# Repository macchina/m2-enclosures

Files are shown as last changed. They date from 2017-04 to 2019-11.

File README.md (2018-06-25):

# M2 Enclosures

We've designed a few 3-D printable enclosures that fit M2. Feel free to print, edit, tweak and share what you've made!

This repository contains 4 possible case variations:

* Under-the-hood (UTH) 
* Under-the-hood (UTH) with additional space for XBee modules
* Under-the-dash (UTD)
* Under-the-dash (UTD) with additional space for XBee modules

Any Gcode files are created with Cura for use on an Ultimaker 2 machine. Unless you have the same machine, you'll probably want to re-slice from STL file for your machine.

#### Note: Use the latest M2R3 versions for best fitting enclosures ####

 Our release hardware uses V-scored PCBs, which result in a little more material on the edges of the PCBs. We've updated the enclosure design to address this, so please use the "M2R3" versions.

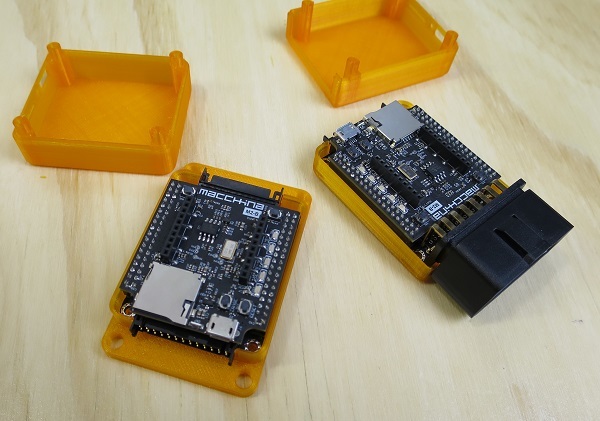
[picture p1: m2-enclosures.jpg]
Picture of printed cases


 We used 4 of [these](https://www.mcmaster.com/#90380a011/=179tb2t) screws in each assembly. We like this translucent plastic so you can see the 5 single-color LEDs through the case. These were printed on an Ultimaker 2 machine.

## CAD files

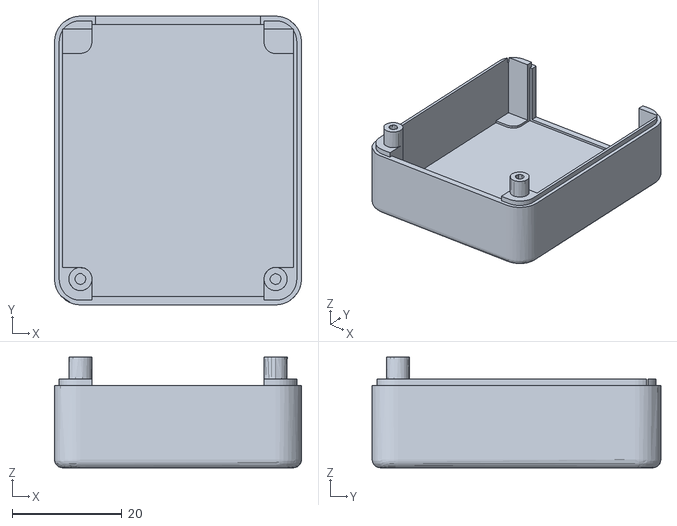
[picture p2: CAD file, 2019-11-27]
P1BETA-UTH_TOP.stl
45.0 x 52.6 x 20.1

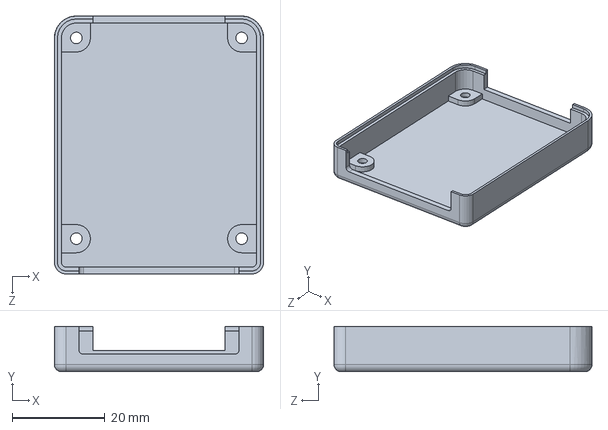
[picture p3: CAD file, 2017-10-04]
M2R3_CASE_BOTTOM_UTD.SLDPRT
45.0 x 9.75 x 55.5 mm

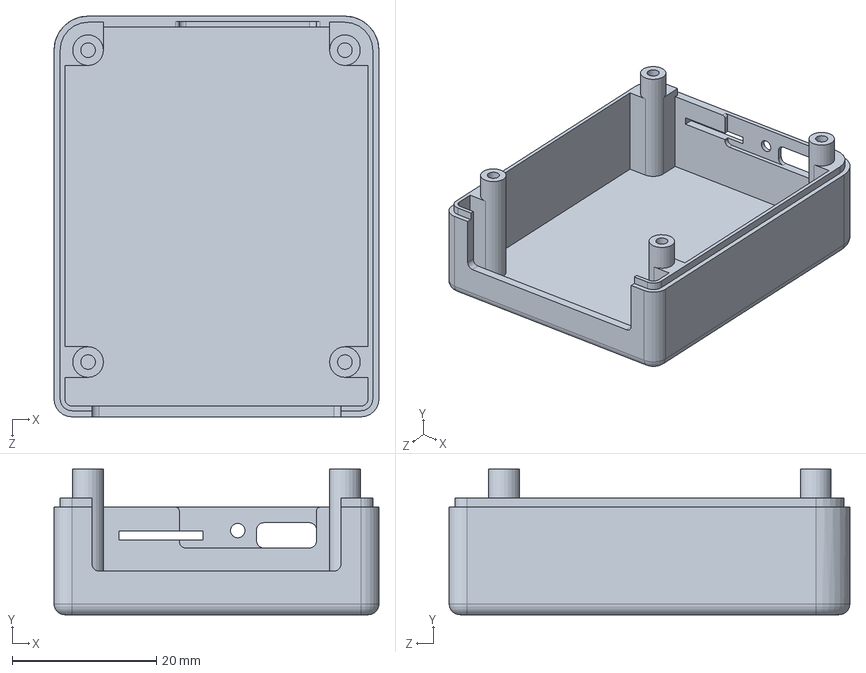
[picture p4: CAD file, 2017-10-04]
M2R3_CASE_TOP_UTD.SLDPRT
45.0 x 20.1 x 55.5 mm

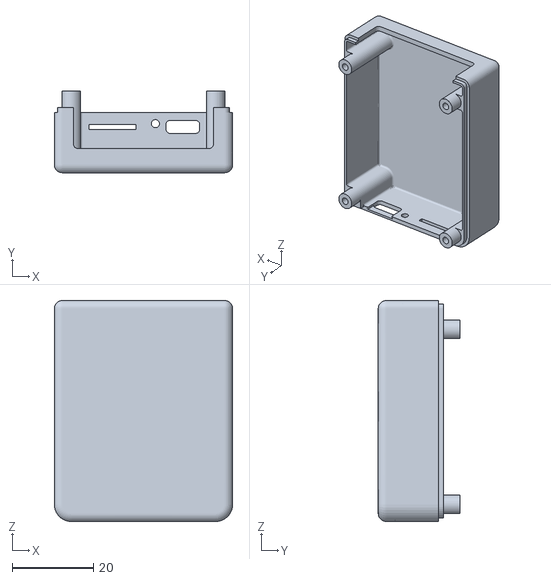
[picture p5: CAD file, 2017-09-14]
M2R2_XBEE_CASE_TOP_UTD.stl
44.0 x 20.1 x 54.5

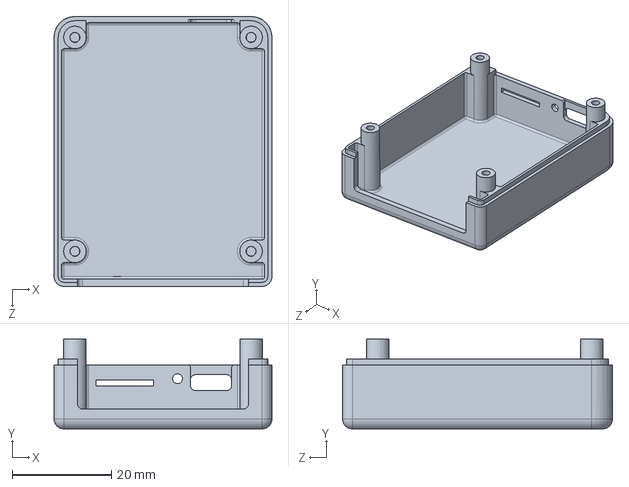
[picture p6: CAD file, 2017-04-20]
M2R2_CASE_TOP_UTD.SLDPRT
44.0 x 18.1 x 54.5 mm

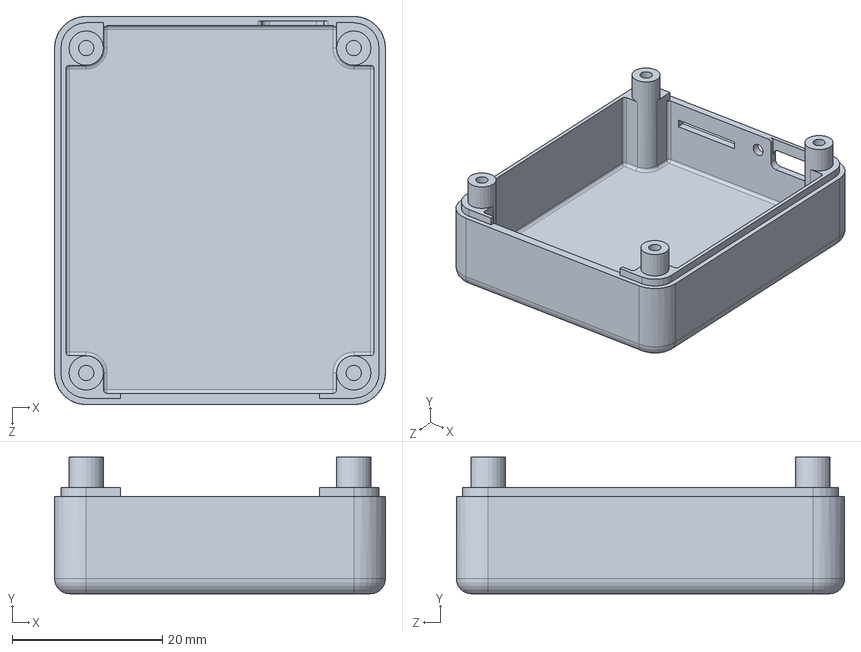
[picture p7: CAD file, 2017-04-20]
M2R2_CASE_TOP_UTH.SLDPRT
44.0 x 18.1 x 51.6 mm

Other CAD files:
ARCHIVE/M2R2_CASE_BOTTOM_UTH.STL
ARCHIVE/M2R2_CASE_TOP_UTD.STL
ARCHIVE/M2R2_CASE_TOP_UTH.STL
ARCHIVE/M2R3_CASE_BOTTOM_UTD.STL
ARCHIVE/M2R3_CASE_TOP_UTD.STL
M2R2_CASE_BOTTOM_UTH.STL
M2R2_CASE_TOP_UTD.STL
M2R2_CASE_TOP_UTH.STL
M2R3_CASE_BOTTOM_UTD.STL
M2R3_CASE_TOP_UTD.STL
M2R3_UTD_BOTTOM.STL
M2R3_UTD_TOP.STL
M2R3_UTD_TOP_SHORT.STL
M2R3_UTH_BOTTOM.STL
M2R3_UTH_TOP.STL
M2R3_UTH_TOP_SHORT.STL

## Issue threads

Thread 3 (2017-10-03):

Enclosure does not fit M2 received from Kickstarter campaign.

Jfunct, 2017-10-03:
I printed the enclosure files in this repo, and there's a considerable amount of error in the screw boss positions relative to the mounting holes on the PCB.  I can't even get the enclosure to fit around the stack, because the bosses interfere with the corner cut-outs on the mezzanine board.

Has the PCB design changed mechanically since this enclosure CAD work was done?

rocketjosh, 2017-10-04:
The PCB dimensions and hole locations did not change between R2 (beta) and R3 (release). However, we used a V-scored PCB in R3, so that may require a little more interior clearance in the enclosures. We've added a couple new files to this repo:

M2R3_CASE_TOP_UTD (STL and Solidworks)
M2R3_CASE_BOTTOM_UTD (STL and Solidworks)

These parts should have a bit more slop on the inside walls to allow for that V-scored PCB edge.

Give those a shot and let us know how they work out.

Jfunct, 2017-10-19:
Thanks gentlemen - the new design does indeed fit better.

Closed 2017-10-19.

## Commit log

2016-05-06 Rearranged and added M2.0 3D print files
    [R1_CASE_BOTTOM_1.0.STL, R1_CASE_TOP_1.0.STL]
2017-04-20 updating design, adding Solidworks and gcode versions
    [M2R2_CASE_BOTTOM_UTD.SLDPRT, M2R2_CASE_BOTTOM_UTD.STL, M2R2_CASE_BOTTOM_UTH.SLDPRT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]
2017-09-14 Added 2mm to the top to fit most XBee modules
    [M2R2_XBEE_CASE_TOP_UTD.stl]
2017-10-04 Adding R3 UTD version with more interior clearance
    [M2R3_CASE_BOTTOM_UTD.SLDPRT, M2R3_CASE_BOTTOM_UTD.STL, M2R3_CASE_TOP_UTD.SLDPRT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]
2018-06-25 Added UTH versions, archived M2R2 versions.
    [M2R2_CASE_BOTTOM_UTD.SLDPRT, M2R2_CASE_BOTTOM_UTD.STL, M2R2_CASE_BOTTOM_UTH.SLDPRT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]
2019-11-02 Beta Design
    [P1BETA-UTH_TOP.stl]
